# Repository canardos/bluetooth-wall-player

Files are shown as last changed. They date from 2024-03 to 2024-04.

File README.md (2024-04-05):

# Bluetooth Wall Audio Player

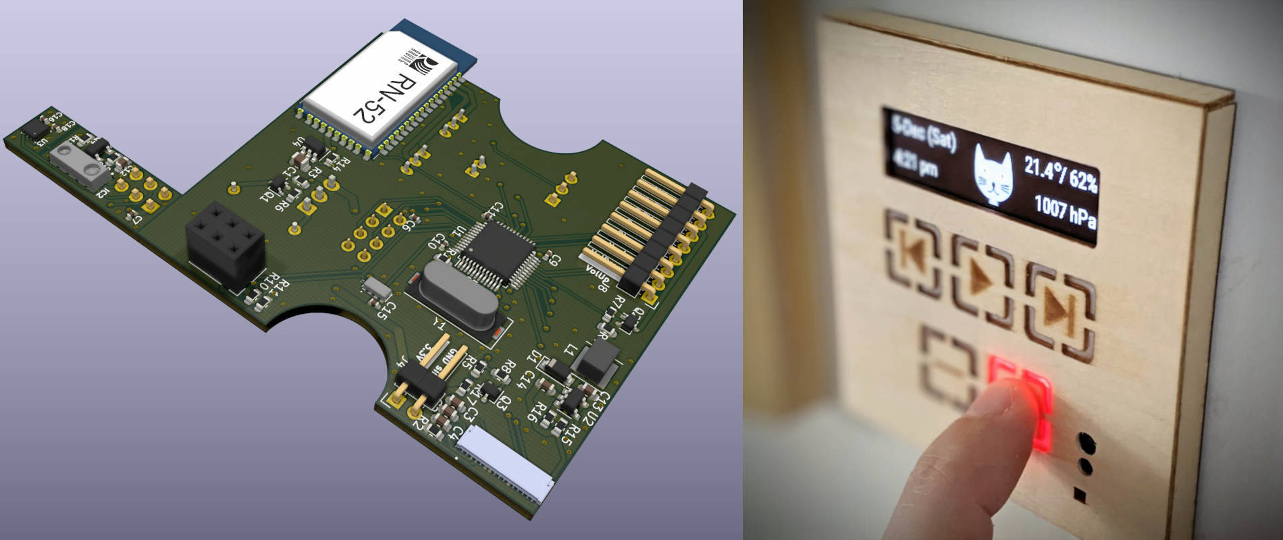
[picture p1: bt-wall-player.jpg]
Bluetooth audio player


## A low power, wall mounted, Bluetooth audio player, clock, and environmental monitor

> [!Warning]
> This is personal project. It was built and works without issue for my purposes. It is made public here in case some part of it is useful to others, but **neither the hardware nor firmware have been rigorously tested**.

**Features:**

- Media/volume controls
- Song metadata display
- Time, temperature, pressure, humidity display on idle
- Ultra low power sleep with proximity sensing wakeup
- Differential analog and S/PDIF digital audio output

**This repo contains the firmware and PCB/enclosure design.**

**See [custom electronics projects at duk.io](https://www.duk.io/blog/electronics-projects/) for full project details.**

## Build

The project uses the [PlatformIO](https://platformio.org/) dependency management/build system. If you have PlatformIO installed, executing the `run` command in the root folder *should* 🙏 be all that is required for a successful build. The `platformio.ini` file contains the required configuration  and PlatformIO will download the required platform dependencies and toolchain.

**1. Clone repo and download submodules**

```shell
> git clone https://github.com/canardos/bluetooth-wall-player.git
> cd bluetooth-wall-player
> git submodule update --init
```

**2. Build firmware (PlatformIO must be installed)**

```shell
> pio run

```

**3. Upload to device**

Similarly, use `pio run --target upload` to upload the firmware to the device. You'll likely need to update the upload settings in `platformio.ini` to reflect your settings, or use your own upload tool.

```shell
> pio run --target upload

```

**4. [optional] Create project files for IDE**

If you want to view/edit the project in your favorite IDE, use PlatformIO to generate the appropriate setup/workspace files and import the project:

```shell
> pio project init --ide [atom|clion|codeblocks|eclipse|emacs|netbeans|qtcreator|sublimetext|vim|visualstudio|vscode]
```

See the [PlatformIO documentation](https://docs.platformio.org) for further details.

#### Using an alternate build system

**Platform dependencies**

If you wish to use a different build system, you will need:

| | |
|-|-|
| ST STM32 CMSIS headers | Peripheral/register definitions |
| CMSIS headers/source | CMSIS HAL functionality - SysTick_Config, NVIC_xxx etc.|
| CMSIS Cortex-M3 system source | `SystemInit()`/`SystemCoreClockUpdate()` implementation and `SystemCoreClock`|
| Startup source file | ASM file containing the startup code and vector table |
| Linker script | Tells the linker how to setup everything in flash/SRAM |

All of these are available in the [STM32 SDK](https://www.st.com/en/development-tools/stm32-software-development-tools.html) available from ST Micro.

**Compiling / linking**

`platformio.ini` lists the required compiler flags. Be sure to use `--specs=nano.specs` and `--specs=nosys.specs` when linking using your own tools.

#### Compiler

The project was built with `gcc-arm-none-eabi 9.2.1` It should work with any later GCC version and possibly with other compilers. The code contains some GCC flags and some C99 VLAs.

#### Target requirements

| | |
|-|-|
|MCU  | STM32F1xx |
|Flash| >42kb |
|SRAM | >8kb |

## Dependencies (firmware)

**CMSIS**

PlatformIO should automatically include/link the correct headers/sources from the STM32 SDK. Version 9.0.0 was used in production.

**Libpekin**

[Libpekin](https://github.com/canardos/libpekin) is a collection of shared MCU-related code resulting from this and other projects. It's included as a Git submodule in the `lib` folder. PlatformIO will include the `lib` subfolders automatically.

## Hardware

#### PCB

The PCB was designed with KiCad v.5, but the files have been upgraded to v.7 and are located in `/hardware/pcb`. Gerber output for the first revision is located in `/hardware/pcb/plots_rev_a`.

> [!Important]
> [Several fixes have been made to the design](https://www.duk.io/blog/electronics-projects/bt-player/bluetooth-audio-player-conclusion/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), which are implemented in the latest schematic/pcb files, but are not present in the revision A plot output.

See the [KiCad documentation](https://docs.kicad.org/) for information on installing and using KiCad.

**Custom symbols and footprints required by the board are included as a Git submodule at `/hardware/pcb/kicad-mycustom-lib`, and are included in the KiCad project as a project-specific library.**

#### Enclosure

The [enclosure design](http://www.duk.io/blog/electronics-projects/bt-player/bluetooth-audio-player-mechanical-design/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) includes a [laser-cut wooden facade](http://www.duk.io/blog/electronics-projects/bt-player/bluetooth-audio-player-mechanical-design/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). The CAD files for the design are located in `/hardware/enclosure/laser_cut_facade`.

A Sketchup model I used to model the mechanical constraints of the design is included in `/hardware/enclosure`.

## Folder structure

```
BTWallPlayer
|
+--artwork           | SVG sources for animation
|  |
|  +--render         | bitmap output frames
|
+--hardware
|  |
|  +--pcb           | KiCad schematic and board design files
|  +--enclosure     | Enclosure Sketchup model and laser cutting
|                   | design files
|
+--lib
|  |
|  +--libpekin       | Libpekin platform independent code
|  +--libpekin_stm32 | Libpekin STM32 specific code
|
+--src
|  |
|  +--data           | Image and font data
|  +--devices        | Hardware device drivers
|
|--test              | No tests in use

```

## License

This software is available under the [MIT license](https://opensource.org/license/MIT).

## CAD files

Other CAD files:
hardware/enclosure/bt-wall-player.skp

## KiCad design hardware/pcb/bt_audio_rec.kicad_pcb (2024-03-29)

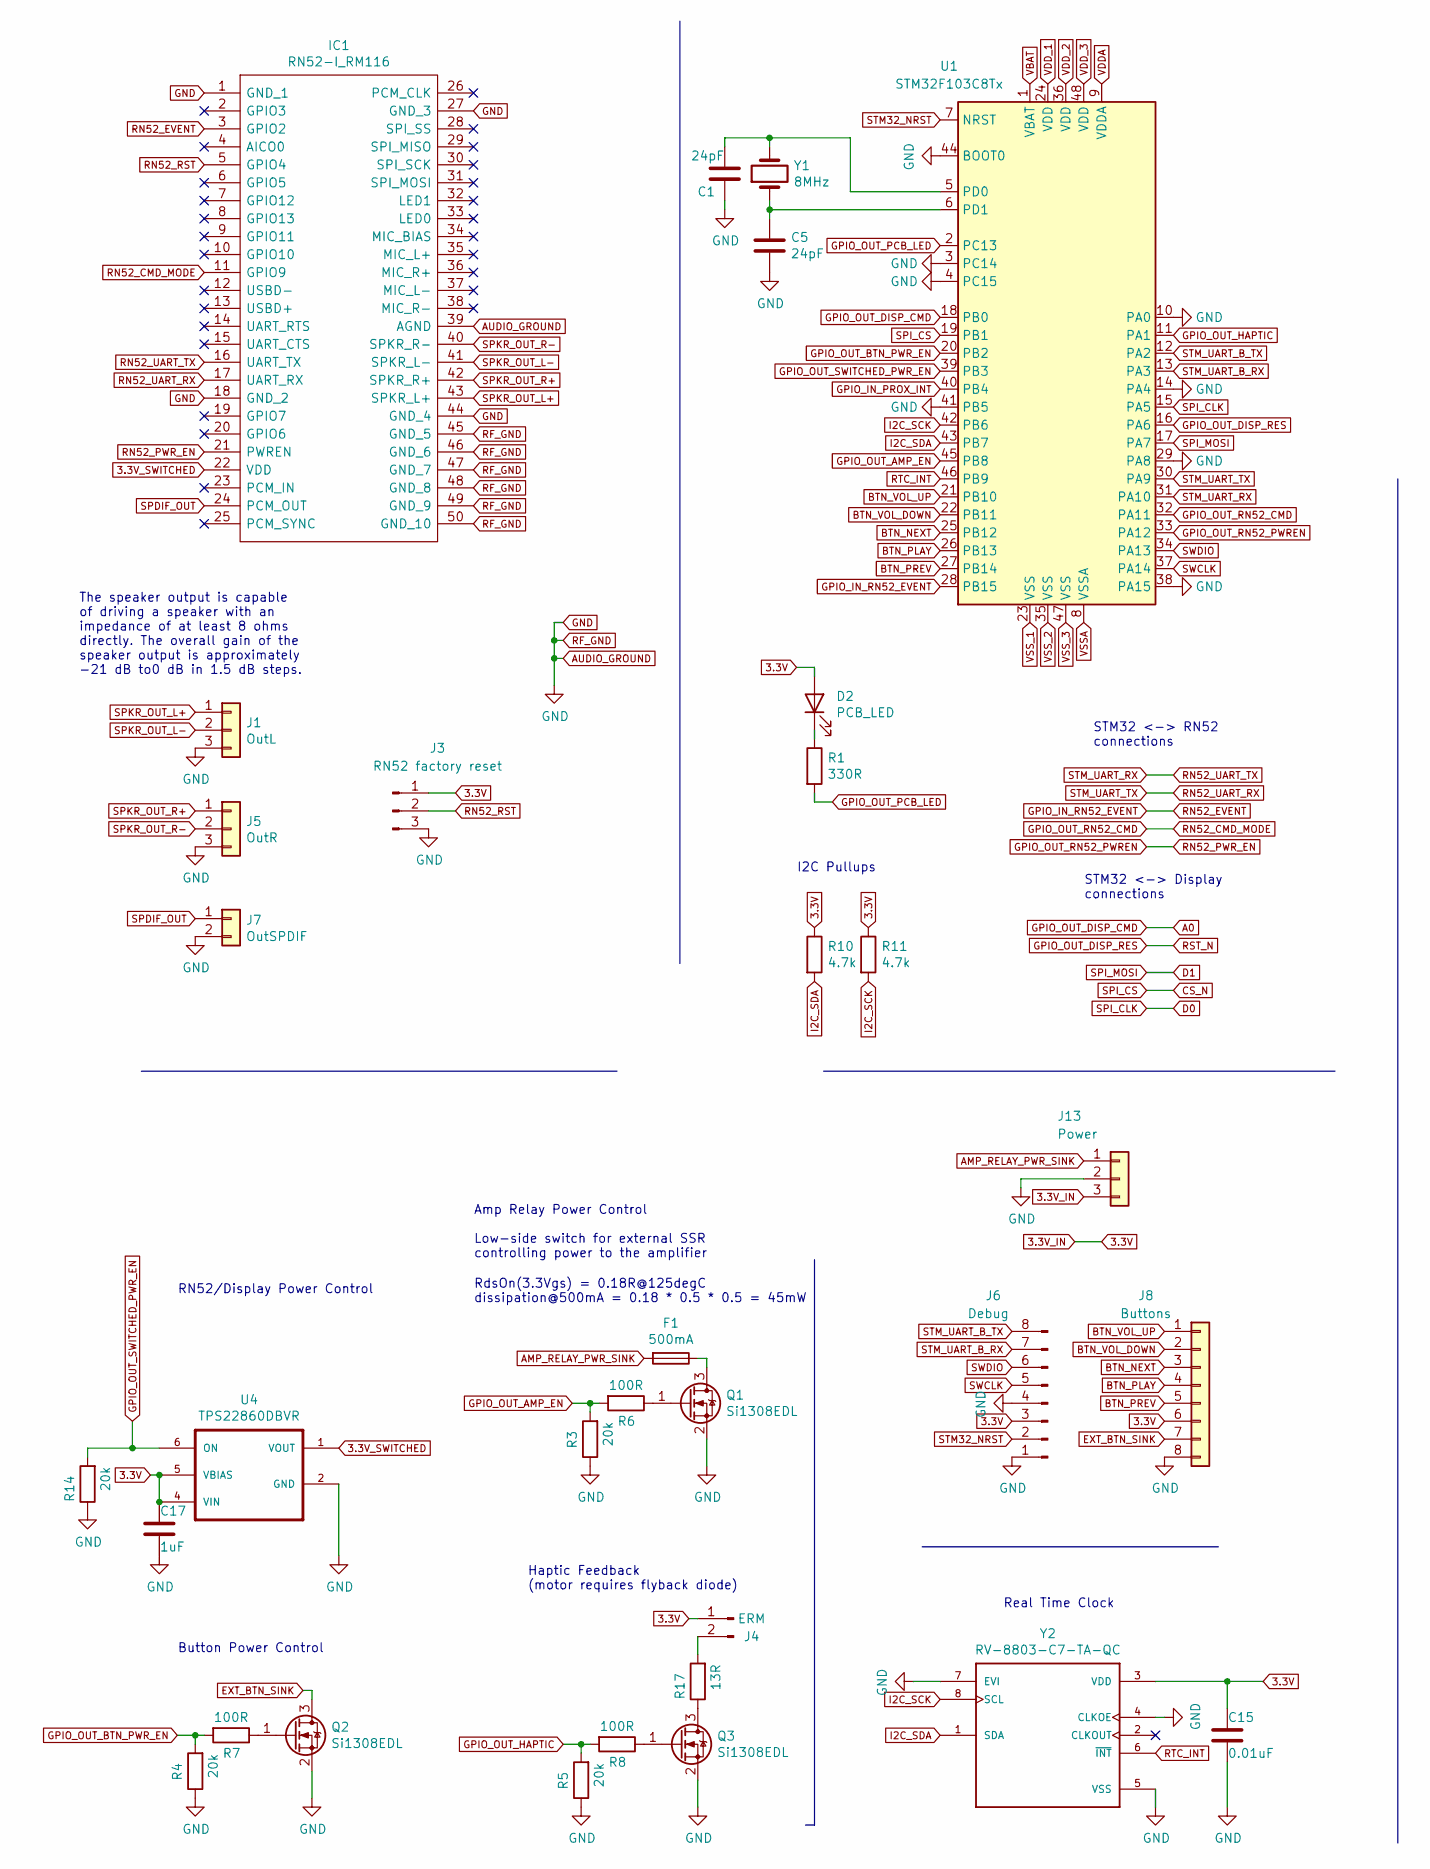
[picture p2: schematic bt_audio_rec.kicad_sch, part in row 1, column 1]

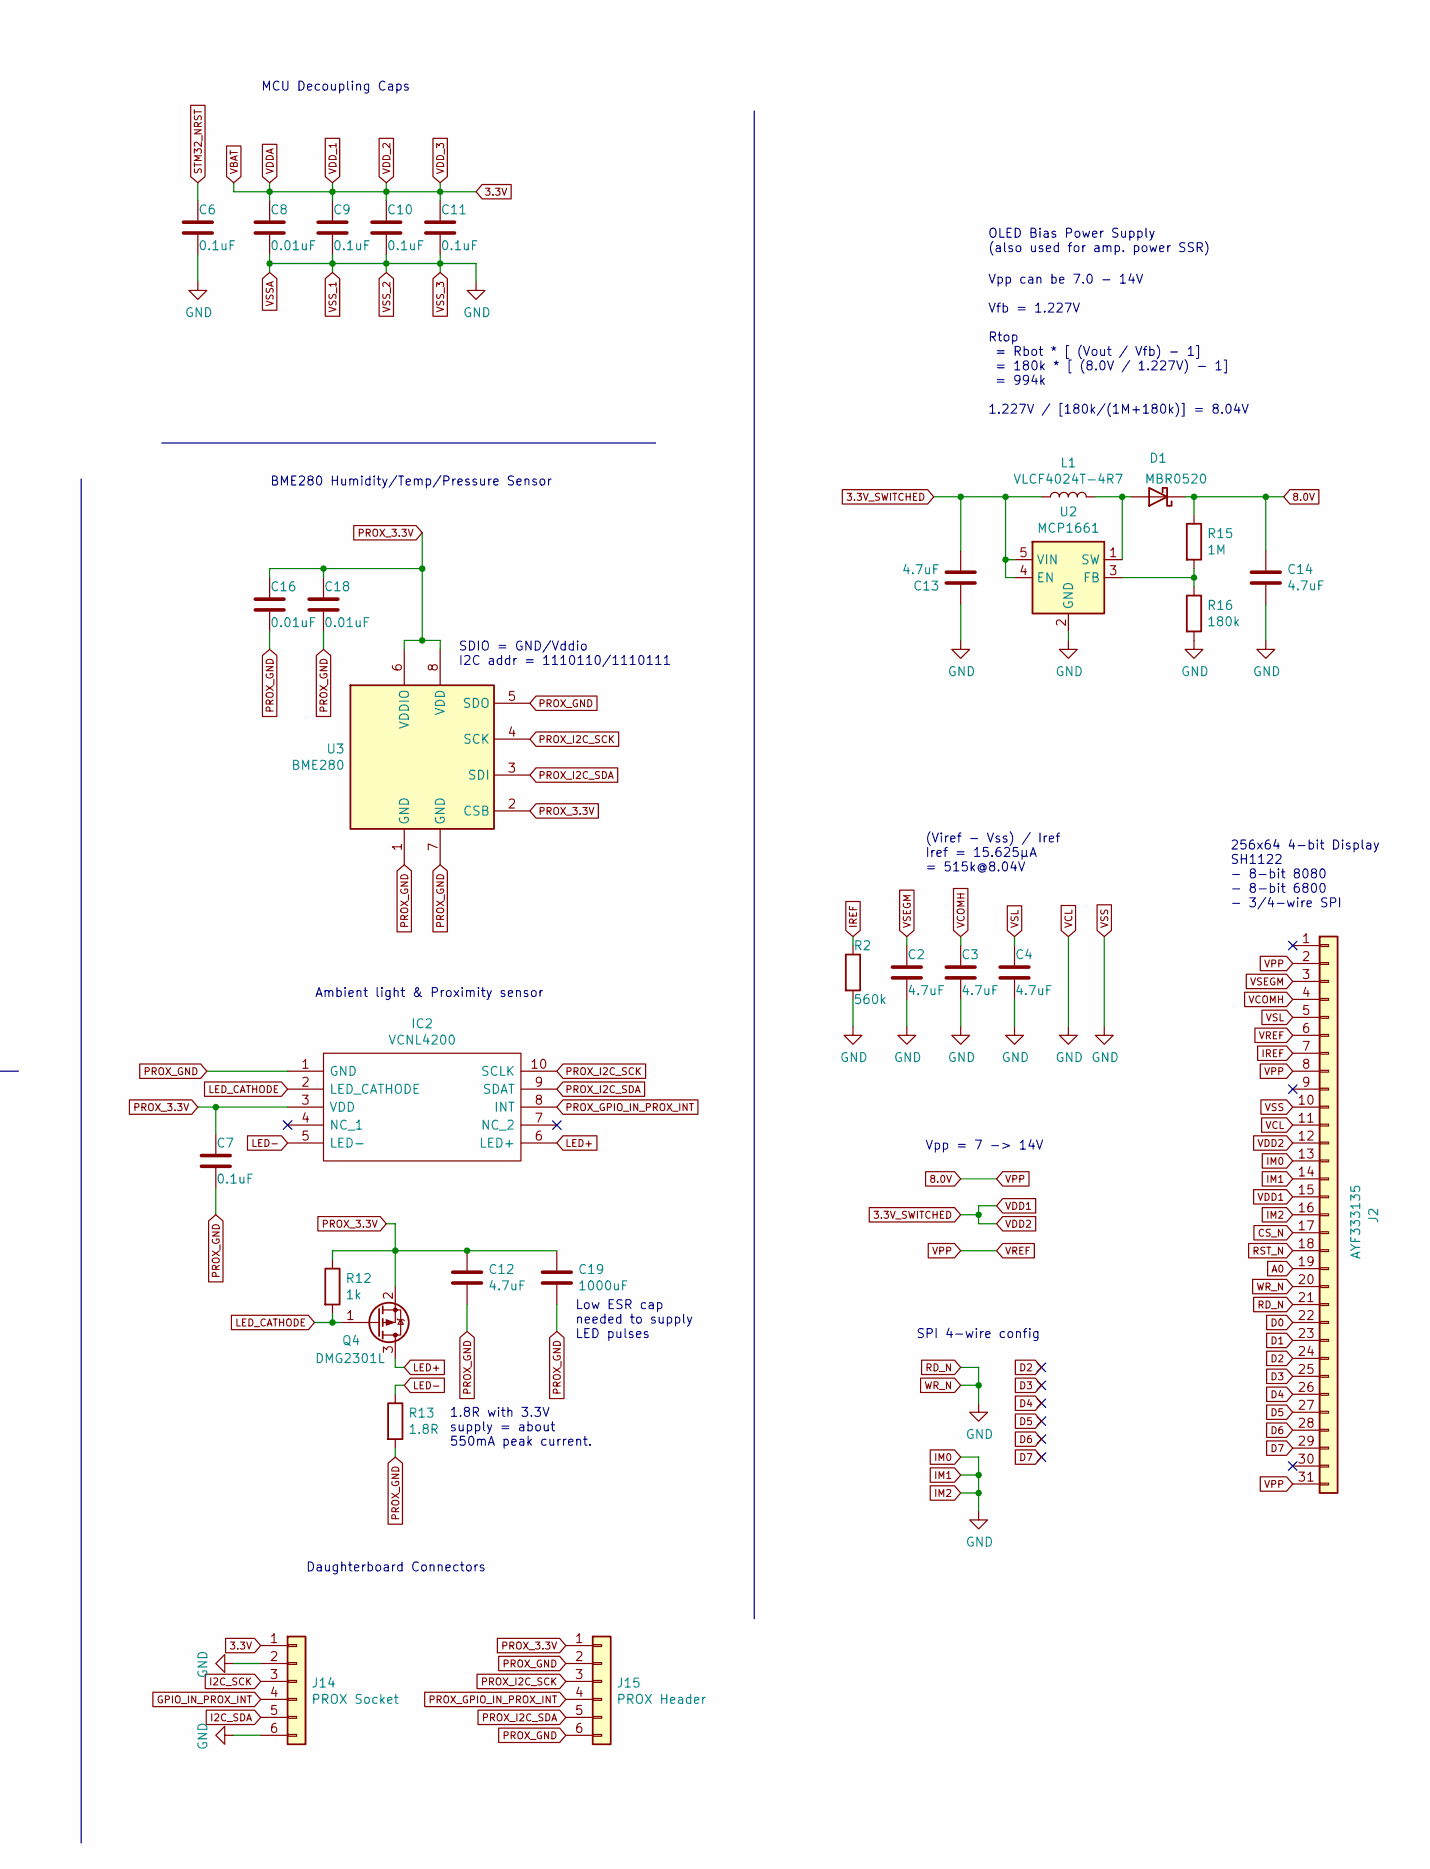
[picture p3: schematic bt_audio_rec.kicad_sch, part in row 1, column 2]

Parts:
C1, C5: 24pF; C_0402_1005Metric
C2, C3, C4, C12, C13, C14: 4.7uF; C_0603_1608Metric
C6, C7, C9, C10, C11: 0.1uF; C_0402_1005Metric
C8, C15, C16, C18: 0.01uF; C_0402_1005Metric
C17: 1uF; C_0805_2012Metric
C19: 1000uF; C_Radial_D6.3mm_H7.0mm_P2.50mm
D1: MBR0520; D_SOD-123
D2: PCB_LED; D_0603_1608Metric
F1: 500mA; R_Axial_DIN0207_L6.3mm_D2.5mm_P10.16mm_Horizontal
IC1: RN52-I_RM116; Bluetooth_module_Microchip_RN52; Manufacturer_Part_Number RN52-I/RM116; Mouser Part Number 579-RN52-I/RM116
IC2: VCNL4200; Proximity_Sensor_Vishay_VCNL4200; Manufacturer_Part_Number VCNL4200; Mouser Part Number 78-VCNL4200
J1: OutL; JST_PH_B3B-PH-K_1x03_P2.00mm_Vertical
J2: AYF333135; FPC_Socket_0.3_31_Panasonic_AYF333135
J3: RN52 factory reset; PinHeader_1x03_P2.54mm_Horizontal
J4: ERM; PinHeader_1x02_P2.54mm_Horizontal
J5: OutR; JST_PH_B3B-PH-K_1x03_P2.00mm_Vertical
J6: Debug; PinSocket_2x04_P2.54mm_Vertical
J7: OutSPDIF; JST_PH_B2B-PH-K_1x02_P2.00mm_Vertical
J8: Buttons; PinHeader_1x08_P2.54mm_Horizontal
J13: Power; Molex_KK-254_AE-6410-03A_1x03_P2.54mm_Vertical
J14: PROX Socket; PinSocket_2x03_P2.54mm_Vertical
J15: PROX Header; PinHeader_2x03_P2.54mm_Vertical
L1: VLCF4024T-4R7; Inductor_L_TDK_VLCF4024
Q1, Q2, Q3: Si1308EDL; SOT-323_SC-70
Q4: DMG2301L; SOT-23
R1: 330R; R_0603_1608Metric
R2: 560k; R_0603_1608Metric
R3, R4, R5, R14: 20k; R_0603_1608Metric
R6, R7, R8: 100R; R_0603_1608Metric
R10, R11: 4.7k; R_0603_1608Metric
R12: 1k; R_0603_1608Metric
R13: 1.8R; R_0603_1608Metric
R15: 1M; R_0603_1608Metric
R16: 180k; R_0603_1608Metric
R17: 13R; R_0603_1608Metric
U1: STM32F103C8Tx; LQFP-48_7x7mm_P0.5mm
U2: MCP1661; SOT-23-5
U3: BME280; Bosch_LGA-8_2.5x2.5mm_P0.65mm_ClockwisePinNumbering
U4: TPS22860DBVR; SOT-23-6
Y1: 8MHz; Crystal_SMD_HC49-SD
Y2: RV-8803-C7-TA-QC; RTC_Microcrystal_RV-8803-C7-TA-QC

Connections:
3.3V: C8.1, C9.1, C10.1, C11.1, C15.1, C17.1, D2.2 (A), J3.1, J4.1, J6.3, J8.6, J13.3, J14.1, R10.1, R11.1, U1.1 (VBAT), U1.9 (VDDA), U1.24 (VDD), U1.36 (VDD), U1.48 (VDD), U4.4 (VIN), U4.5 (VBIAS), Y2.3 (VDD)
3.3V_SWITCHED: C13.2, IC1.22 (VDD), J2.12, J2.15, L1.1, U2.4 (EN), U2.5 (VIN), U4.1 (VOUT)
8.0V: C14.1, D1.1 (K), J2.2, J2.6, J2.8, J2.31, R15.1
A0: J2.19, U1.18 (PB0)
AMP_RELAY_PWR_SINK: F1.2, J13.1
AUDIO_GROUND: C1.1, C2.2, C3.2, C4.2, C5.2, C6.2, C8.2, C9.2, C10.2, C11.2, C13.1, C14.2, C15.2, C17.2, IC1.1 (GND_1), IC1.18 (GND_2), IC1.27 (GND_3), IC1.39 (AGND), IC1.44 (GND_4), IC1.45 (GND_5), IC1.46 (GND_6), IC1.47 (GND_7), IC1.48 (GND_8), IC1.49 (GND_9), IC1.50 (GND_10), J1.3, J2.10, J2.11, J2.13, J2.14, J2.16, J2.20, J2.21, J3.3, J5.3, J6.1, J6.4, J7.2, J8.8, J13.2, J14.2, J14.6, Q1.2 (S), Q2.2 (S), Q3.2 (S), R2.2, R3.1, R4.1, R5.1, R14.1, R16.2, U1.3 (PC14), U1.4 (PC15), U1.8 (VSSA), U1.10 (PA0), U1.14 (PA4), U1.23 (VSS), U1.29 (PA8), U1.35 (VSS), U1.38 (PA15), U1.41 (PB5), U1.44 (BOOT0), U1.47 (VSS), U2.2 (GND), U4.2 (GND), Y2.4 (CLKOE), Y2.5 (VSS), Y2.7 (EVI)
BTN_NEXT: J8.3, U1.25 (PB12)
BTN_PLAY: J8.4, U1.26 (PB13)
BTN_PREV: J8.5, U1.27 (PB14)
BTN_VOL_DOWN: J8.2, U1.22 (PB11)
BTN_VOL_UP: J8.1, U1.21 (PB10)
CS_N: J2.17, U1.19 (PB1)
D0: J2.22, U1.15 (PA5)
D1: J2.23, U1.17 (PA7)
D2: J2.24
D3: J2.25
D4: J2.26
D5: J2.27
D6: J2.28
D7: J2.29
EXT_BTN_SINK: J8.7, Q2.3 (D)
GPIO_IN_PROX_INT: J14.4, U1.40 (PB4)
GPIO_IN_RN52_EVENT: IC1.3 (GPIO2), U1.28 (PB15)
GPIO_OUT_AMP_EN: R3.2, R6.2, U1.45 (PB8)
GPIO_OUT_BTN_PWR_EN: R4.2, R7.2, U1.20 (PB2)
GPIO_OUT_DISP_RES: J2.18, U1.16 (PA6)
GPIO_OUT_HAPTIC: R5.2, R8.2, U1.11 (PA1)
GPIO_OUT_PCB_LED: R1.2, U1.2 (PC13)
GPIO_OUT_RN52_CMD: IC1.11 (GPIO9), U1.32 (PA11)
GPIO_OUT_RN52_PWREN: IC1.21 (PWREN), U1.33 (PA12)
GPIO_OUT_SWITCHED_PWR_EN: R14.2, U1.39 (PB3), U4.6 (ON)
I2C_SCK: J14.3, R11.2, U1.42 (PB6), Y2.8 (SCL)
I2C_SDA: J14.5, R10.2, U1.43 (PB7), Y2.1 (SDA)
IREF: J2.7, R2.1
LED+: IC2.6 (LED+), Q4.3 (D)
LED-: IC2.5 (LED-), R13.1
LED_CATHODE: IC2.2 (LED_CATHODE), Q4.1 (G), R12.2
unnamed: C1.2, U1.5 (PD0), Y1.2
unnamed: C5.1, U1.6 (PD1), Y1.1
unnamed: D1.2 (A), L1.2, U2.1 (SW)
unnamed: D2.1 (K), R1.1
unnamed: F1.1, Q1.3 (D)
unnamed: J4.2, R17.2
unnamed: Q1.1 (G), R6.1
unnamed: Q2.1 (G), R7.1
unnamed: Q3.1 (G), R8.1
unnamed: Q3.3 (D), R17.1
unnamed: R15.2, R16.1, U2.3 (FB)
PROX_3.3V: C7.1, C12.1, C16.1, C18.1, C19.1, IC2.3 (VDD), J15.1, Q4.2 (S), R12.1, U3.2 (CSB), U3.6 (VDDIO), U3.8 (VDD)
PROX_GND: C7.2, C12.2, C16.2, C18.2, C19.2, IC2.1 (GND), J15.2, J15.6, R13.2, U3.1 (GND), U3.5 (SDO), U3.7 (GND)
PROX_GPIO_IN_PROX_INT: IC2.8 (INT), J15.4
PROX_I2C_SCK: IC2.10 (SCLK), J15.3, U3.4 (SCK)
PROX_I2C_SDA: IC2.9 (SDAT), J15.5, U3.3 (SDI)
RN52_RST: IC1.5 (GPIO4), J3.2
RN52_UART_RX: IC1.17 (UART_RX), U1.30 (PA9)
RN52_UART_TX: IC1.16 (UART_TX), U1.31 (PA10)
RTC_INT: U1.46 (PB9), Y2.6 (~INT)
SPDIF_OUT: IC1.24 (PCM_OUT), J7.1
SPKR_OUT_L+: IC1.43 (SPKR_L+), J1.1
SPKR_OUT_L-: IC1.41 (SPKR_L-), J1.2
SPKR_OUT_R+: IC1.42 (SPKR_R+), J5.1
SPKR_OUT_R-: IC1.40 (SPKR_R-), J5.2
STM32_NRST: C6.1, J6.2, U1.7 (NRST)
STM_UART_B_RX: J6.7, U1.13 (PA3)
STM_UART_B_TX: J6.8, U1.12 (PA2)
SWCLK: J6.5, U1.37 (PA14)
SWDIO: J6.6, U1.34 (PA13)
VCOMH: C3.1, J2.4
VSEGM: C2.1, J2.3
VSL: C4.1, J2.5

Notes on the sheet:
Haptic Feedback (motor requires flyback diode)
Daughterboard Connectors
I2C Pullups
Amp Relay Power Control Low-side switch for external SSR controlling power to the amplifier
Vpp can be 7.0 - 14V Vfb = 1.227V Rtop = Rbot * [ (Vout / Vfb) - 1] = 180k * [ (8.0V / 1.227V) - 1] = 994k 1.227V / [180k/(1M+180k)] = 8.04V
BME280 Humidity/Temp/Pressure Sensor
SDIO = GND/Vddio I2C addr = 1110110/1110111
(Viref - Vss) / Iref Iref = 15.625μA = 515k@8.04V
The speaker output is capable of driving a speaker with an impedance of at least 8 ohms directly. The overall gain of the speaker output is approximately -21 dB to0 dB in 1.5 dB steps.
Low ESR cap needed to supply LED pulses
Button Power Control
RdsOn(3.3Vgs) = 0.18R@125degC dissipation@500mA = 0.18 * 0.5 * 0.5 = 45mW
1.8R with 3.3V supply = about 550mA peak current.
Vpp = 7 -> 14V
STM32 <-> Display connections
Ambient light & Proximity sensor
RN52/Display Power Control
OLED Bias Power Supply (also used for amp. power SSR)
Real Time Clock
STM32 <-> RN52 connections
256x64 4-bit Display SH1122 - 8-bit 8080 - 8-bit 6800 - 3/4-wire SPI
MCU Decoupling Caps
SPI 4-wire config

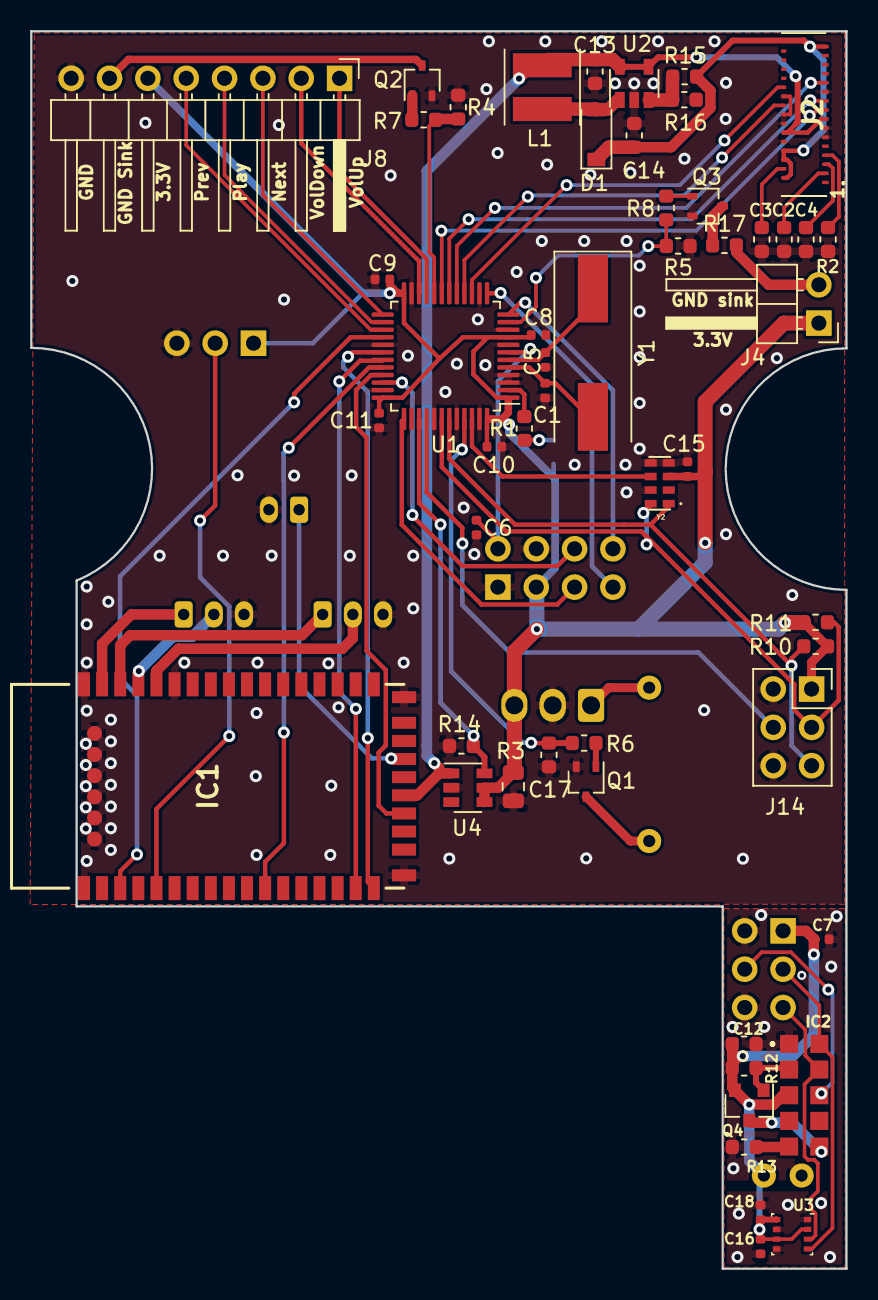
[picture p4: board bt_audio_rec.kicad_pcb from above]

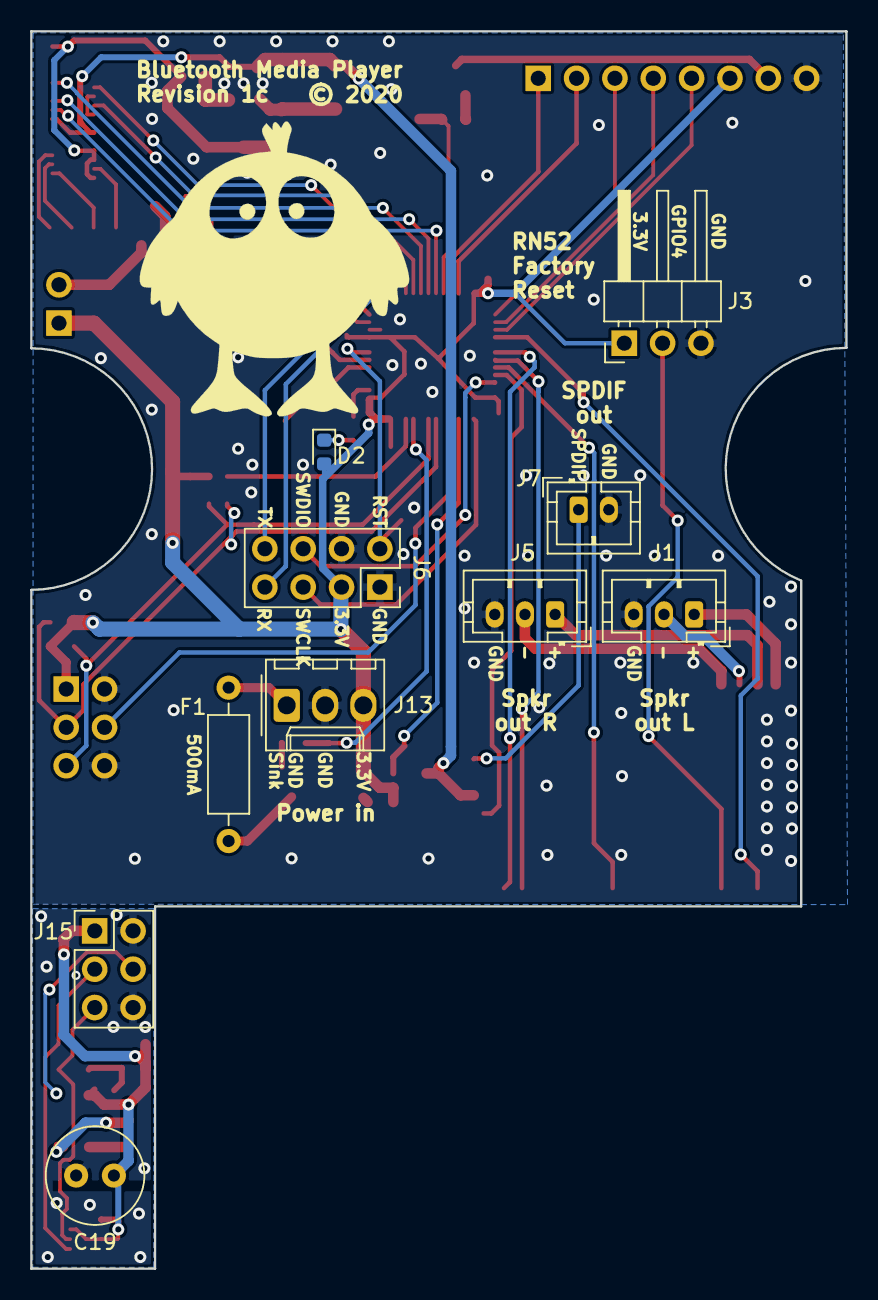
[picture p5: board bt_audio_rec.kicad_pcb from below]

Board: 2 copper layers, 54.0 x 82.0 mm, 62 parts (10 on the bottom side), 64 nets.

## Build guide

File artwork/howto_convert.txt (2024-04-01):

To convert a portion of the SVG to a 4-bit bitmap source for use with Libpekin:

1) Export PNG from inkscape
2) magick cat.png -depth 4 gray:cat.dat
3) xxd -i cat.dat > cat.h

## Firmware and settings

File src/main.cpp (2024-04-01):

#include "libpekin.h"
#include "string_util.h"
#include "libpekin_stm32_hal.h"
#include "clock_stm32f1xx.h"

#include <bt_module.h>
#include <error_handler.h>
#include <event_queue.h>
#include <player_state_machine.h>

#include <devices/peripherals.h>
#include <devices/rn52.h>
#include "devices/oled.h"
#include "devices/sensors.h"
#include "devices/rtc.h"

/*
3.3V / GND / sink
blue /white/brown, left to right front of faceplate
brown/black/blue cable
*/

using namespace Libp;
using namespace LibpStm32;

static BtModule bt_module_(getRn52());
static Display display(getOled());
static PwrControl pwr_ctrl;
static EventQueue queue_;
static PlayerStateMachine player(queue_, bt_module_, display, pwr_ctrl);

void initSysClock()
{
    Clk::setSysClk(Clk::SysClkSrc::ext_high_speed_osc, 2, Clk::PllSrc::hse, 2);
    // 24 MHz
    Clk::setSysClk(Clk::SysClkSrc::pll, 2, Clk::PllSrc::hse, 3);
    // APB1 can't exceed 36 MHz
    Clk::setPeripheralClk(Clk::ApbPrescaler::div1, Clk::ApbPrescaler::div1);
}

void initSensors()
{
    if (!initTempSensor()) {
        getErrHndlr().halt(ErrorCode::module_init_fail, "BME280 init failed");
    }
    if (!initRtc()) {
        getErrHndlr().halt(ErrorCode::module_init_fail, "RTC init failed");
    }

    display.drawText(Display::TextPos::fullscreen, "Calibrating proximity", "in 3");
    delayMs(1000);
    display.drawText(Display::TextPos::fullscreen, "Calibrating proximity", "in 2");
    delayMs(1000);
    display.drawText(Display::TextPos::fullscreen, "Calibrating proximity", "in 1");
    delayMs(1000);

    uint16_t prox_count = initProxSensor();
    if (prox_count == 0) {
        getErrHndlr().halt(ErrorCode::module_init_fail, "Prox init failed");
    }

    constexpr uint8_t max_len = strlen("Done ()") + Libp::maxStrLen<uint16_t>();
    char buf[max_len];
    snprintf(buf, max_len, "Done (%d)", prox_count);
    display.drawText(Display::TextPos::fullscreen, buf, "Initializing Bluetooth...");

    TimeData time_data = {0};
    time_data.year = 20;
    time_data.month = 1;
    time_data.day_of_month = 1;
    setTime(time_data);
}

//#define TEST_PROX_MODE

#ifdef TEST_PROX_MODE
void drawProx()
{
    char buf[50];
    while (true) {
        uint16_t count = getProxCount();
        snprintf(buf, 50, "Count: %d", count);
        display.drawText(Display::TextPos::fullscreen, buf, "");
        delayMs(300);
    }
}
#endif

void initPeripherals()
{
    initGpio();  // enable GPIO clocks before peripherals init
    initSerial();
    initSpi();
    initI2c();
    initTimers();
    initErrHndlr();
}

int main(void)
{
    initSysClock();
    libpekinInitTimers();
    initPeripherals();
    pwr_ctrl.setState(PwrControl::PwrState::clock); // needs errHndlr
    oledInit();                                     // needs SPI and timers
    initSensors();                                  // needs I2C, timers, and display
#ifdef TEST_PROX_MODE
    drawProx();
#endif
    initRn52();
    if (!bt_module_.init()) {
        getErrHndlr().halt(ErrorCode::module_init_fail, "BT init failed");
    }
    enableExtIrqs();
    clearProxInterrupt();
    player.run();
}

#ifdef __cplusplus
extern "C" {
#endif

/// Triggered by RN52 event on GPIO2 and button presses
__attribute__ ((interrupt("IRQ")))
void EXTI15_10_IRQHandler(void)
{
    disableExtIrqs();
    getErrHndlr().report("\r\nEXTI15_10_IRQ\r\n");

    // --- RN52 event ---

    if (Pins::rn52_gpio2.irqIsPending()) {
        queue_.postEvent(EventType::rn52_gpio2);
        Pins::rn52_gpio2.clearPendingIrqBit();
    }

    // --- Button events ---

    if (Pins::btn_play.irqIsPending()) {
        bool pressed = Pins::btn_play.read();
        getErrHndlr().report("Play: %d\r\n", (int)pressed);
        queue_.postEvent(pressed ? EventType::btn_play : EventType::btn_play_release);
        Pins::btn_play.clearPendingIrqBit();
    }
    if (Pins::btn_vol_up.irqIsPending()) {
        queue_.postEvent(EventType::btn_vol_up);
        Pins::btn_vol_up.clearPendingIrqBit();
    }
    if (Pins::btn_vol_dn.irqIsPending()) {
        queue_.postEvent(EventType::btn_vol_dn);
        Pins::btn_vol_dn.clearPendingIrqBit();
    }
    if (Pins::btn_next.irqIsPending()) {
        queue_.postEvent(EventType::btn_next);
        Pins::btn_next.clearPendingIrqBit();
    }
    if (Pins::btn_prev.irqIsPending()) {
        queue_.postEvent(EventType::btn_prev);
        Pins::btn_prev.clearPendingIrqBit();
    }
    Pins::btn_prev.clearPendingIrqLine();
    //__DSB();
    enableExtIrqs();
}

/// Triggered by RTC minute tick
__attribute__ ((interrupt("IRQ")))
void EXTI9_5_IRQHandler(void)
{
    getErrHndlr().report("\r\nEXTI9_5_IRQ\r\n");
    if (Pins::rtc_int.irqIsPending()) {
        queue_.postEvent(EventType::clock_tick);
        Pins::rtc_int.clearPendingIrqBit();
    }
    Pins::rtc_int.clearPendingIrqLine();
    __DSB();
}

/// Triggered by proximity sensor
__attribute__ ((interrupt("IRQ")))
void EXTI4_IRQHandler(void)
{
    getErrHndlr().report("\r\nEXTI4_IRQ\r\n");
    if (Pins::proximity_int.irqIsPending()) {
        queue_.postEvent(EventType::proximity_trigger);
        Pins::proximity_int.clearPendingIrqBit();
    }
    Pins::proximity_int.clearPendingIrqLine();
    __DSB();
}

#ifdef __cplusplus
}
#endif

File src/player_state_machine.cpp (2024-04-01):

#include <event_queue.h>
#include <devices/peripherals.h>
#include <devices/haptic.h>
#include <devices/rtc.h>
#include <devices/sensors.h>
#include <display.h>
#include <player_state_machine.h>

using namespace Libp;

PlayerStateMachine::PlayerStateMachine(EventQueue& event_queue,
        BtModule& bt_module, Display& display, PwrControl& pwr_ctrl)
            : event_queue_(event_queue), bt_module_(bt_module),
              display_(display), pwr_ctrl_(pwr_ctrl) { }

// Main program loop
void PlayerStateMachine::run()
{
    pwr_ctrl_.resetInactivityTimer();
    display_.notifyNewModuleState(ModuleState::disconnected, ModuleState::disconnected);
    event_queue_.postEvent(EventType::clock_tick); // paint clock
    while (true) {

        while(event_queue_.eventIsPending())
            processEvent(event_queue_.getNextPendingEvent());

        // Flag set by transition to disconnected state.
        // Need to wait on disconnect animation if we were previously connected
        if (draw_clock_when_display_ready_ && display_.disconnectAnimIsDone() ) {
            draw_clock_when_display_ready_ = false;
            // Start clock animation
            display_.notifyNewModuleState(ModuleState::disconnected, ModuleState::disconnected);
            event_queue_.postEvent(EventType::clock_tick);
        }
        // Detect long press of play button
        if (last_play_press_ms) {
            static constexpr uint32_t long_press_duration_ms = 2000;
            uint32_t now_ms = getMillis();
            if ( (now_ms - last_play_press_ms) > long_press_duration_ms) {
                event_queue_.postEvent(EventType::btn_play_long_press);
                last_play_press_ms = 0;
            }
        }

        if (player_state_ == PlayerState::pairing_listening)
            handlePairingModeListening();

        display_.update();
        oledUpdateBrightness( getLightLvl() );
        sleepIfInactive();

        delayMs(5);
    }
}

static uint32_t lastWakeTime = 0;

void PlayerStateMachine::sleepIfInactive()
{
    if (module_state_ == ModuleState::disconnected && pwr_ctrl_.timeToSleep()) {
        player_state_ = PlayerState::normal;
        pwr_ctrl_.sleep();
        lastWakeTime = getMillis();
        event_queue_.postEvent(EventType::clock_tick);
    }
}

void PlayerStateMachine::processEvent(EventQueue::Event event)
{
    getErrHndlr().report("SM: new event (%s)\r\n", event_type_names[enumBaseT(event.event_)]);
    if (event.event_ != EventType::clock_tick)
        pwr_ctrl_.resetInactivityTimer();

    switch (event.event_) {
    case EventType::rn52_gpio2:
        handleGpio2Event();
        break;
    case EventType::rn52_state_chg:
        handleModuleStateChg(event.new_state_);
        break;
    case EventType::track_chg:
        if (module_state_ == ModuleState::connected_streaming)
            handleTrackChange();
        break;
    case EventType::proximity_trigger:
        clearProxInterrupt();
        // nothing else to do, inactivity timer already reset above
        break;
    case EventType::clock_tick:
        handleClockTick();
        break;
    case EventType::btn_play:
    case EventType::btn_next:
    case EventType::btn_prev:
    case EventType::btn_vol_up:
    case EventType::btn_vol_dn:
    case EventType::btn_play_release:
    case EventType::btn_play_long_press:
        handleBtnPress(event);
        break;
    case EventType::do_nothing_event:
        // nothing to do
        break;
    }
}

void PlayerStateMachine::handleClockTick()
{
    if (module_state_ != ModuleState::disconnected)
        return;

    TimeData time_data;
    EnvData env_data;
    const uint32_t secsActive = (getMillis() - lastWakeTime) / 1000;
    bool success = getTime(time_data) && getTemp(env_data, secsActive);
    if (!success)
        getErrHndlr().halt(ErrCode::i2c, "Sensor failure");

    // Don't draw clock if we are still animating disconnect
    if (!draw_clock_when_display_ready_)
        display_.drawClockAndWeather(time_data, env_data);
}

void PlayerStateMachine::handleBtnPress(EventQueue::Event event)
{
    constexpr bool enable_haptic = false;

    if constexpr (enable_haptic) {
        constexpr uint16_t haptic_duration_ms = 80;
        if (event.event_ != EventType::btn_play_release)
            triggerHaptic(haptic_duration_ms);
    }

    // Track long press for play button
    if (event.event_ == EventType::btn_play)
        last_play_press_ms = getMillis();
    else if (event.event_ == EventType::btn_play_release)
        last_play_press_ms = 0;

    // Delegate to handler for the current state
    (this->*btn_handlers_[enumBaseT(player_state_)])(event);
}

void PlayerStateMachine::handleBtnNormal(EventQueue::Event event)
{
    switch (module_state_) {
    case ModuleState::disconnected:
        if (event.event_ == EventType::btn_play_long_press)
            enterMenuMode();
        break;
    case ModuleState::pairing:
        break;
    case ModuleState::connected:
    case ModuleState::connected_streaming:
        switch(event.event_) {
        case EventType::btn_vol_up:
            bt_module_.volUp();
            break;
        case EventType::btn_vol_dn:
            bt_module_.volDown();
            break;
        case EventType::btn_next:
            bt_module_.trackNext();
            break;
        case EventType::btn_prev:
            bt_module_.trackPrev();
            break;
        case EventType::btn_play:
            bt_module_.playPause();
            break;
        case EventType::btn_play_long_press:
        case EventType::btn_play_release:
            break;
        // Illegal states
        case EventType::rn52_gpio2:
        case EventType::rn52_state_chg:
        case EventType::track_chg:
        case EventType::proximity_trigger:
        case EventType::clock_tick:
        case EventType::do_nothing_event:
            break;
        }
        break;
    }
}

void PlayerStateMachine::handleBtnMenu(EventQueue::Event event)
{
    switch(event.event_) {
    case EventType::btn_prev:
         exitMenuMode();
         break;
    case EventType::btn_play:
        bt_module_.enterPairingMode();
        exitMenuMode();
        break;
    case EventType::btn_next:
        enterSetClockMode();
        break;
    case EventType::btn_vol_up:
        bt_module_.resetPairings();
        display_.drawText(Display::TextPos::fullscreen, "All prior", "pairings cleared");
        delayMs(1800);
        exitMenuMode();
        break;
    case EventType::btn_vol_dn:
        NVIC_SystemReset();
        break;
    case EventType::btn_play_release:
    case EventType::btn_play_long_press:
    case EventType::rn52_gpio2:
    case EventType::rn52_state_chg:
    case EventType::track_chg:
    case EventType::proximity_trigger:
    case EventType::clock_tick:
    case EventType::do_nothing_event:
        break;
    }
}
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

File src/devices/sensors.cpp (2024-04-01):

#include <algorithm>
#include "sensors.h"
#include "drivers/sensors/bme280.h"
#include "drivers/sensors/vcnl_4200.h"
#include "serial/i2c.h"
#include "serial/i2c_bus_stm32f1xx.h"
#include "devices/peripherals.h"
#include "error_handler.h"

using namespace Libp;

constexpr uint32_t i2c_addr = I2C1_BASE;

static I2cWrapper i2c_wrap_bme_(i2c_bus, Bme280::i2c_addr_sdo_gnd);
static I2cWrapper i2c_wrap_prox_(i2c_bus, Vcnl4200::i2c_address);

static Bme280::Bme280 bme280_(i2c_wrap_bme_);
static Vcnl4200::Vcnl4200 vcnl4200_(i2c_wrap_prox_);

#ifndef MOCK_DATA

bool initTempSensor()
{
    return bme280_.initialize()
        && bme280_.reset()
        && bme280_.setConfig(Bme280::Mode::forced,
                // Don't change without updating measure_time_ms below
                Bme280::OSample::osample_x1, Bme280::OSample::osample_x1, Bme280::OSample::osample_x1,
                Bme280::TStandby::ts_10ms,
                Bme280::Filter::coef_16, false);
}
static constexpr uint16_t measure_time_ms = bme280_.maxMeasureTime(true, true, true, 1, 1, 1);


static constexpr Vcnl4200::Vcnl4200Cfg vcnl_cfg = []() {
    using namespace Vcnl4200;
    return Vcnl4200CfgBuilder()
            .alsEnable()
            .psEnable()
            .psLedSetDuty(PsLedDutyCycle::ratio_1_1280)
            .psLedSetDuration(PsLedDuration::it_4t)
            .psLedSetPulses(PsLedNPulses::x8)
            .psIntEnable(PsIntTrigger::closing, 0, 0, PsIntPersistence::x1)
            .build();
}();

uint16_t initProxSensor()
{
    using namespace Vcnl4200;
    bool success = vcnl4200_.configure(vcnl_cfg);

    constexpr uint16_t threshold_margin = 20;
    // Delay until sample is ready
    delayMs(250);
    const uint16_t count = vcnl4200_.psRead();
    const uint16_t threshold = count + threshold_margin;

    getErrHndlr().report("\r\nProx count %d. Threshold = %d\r\n", count, threshold);
    success = success && vcnl4200_.psSetThresholds(threshold, threshold);
    return success
            ? count
            : 0;
}

#ifdef TEST_PROX_MODE
uint16_t getProxCount()
{
    return vcnl4200_.psRead();
}
#endif

uint8_t clearProxInterrupt()
{
    return vcnl4200_.intFlags();
}


// Adjust for heating from proximity sensor/self.
// Using straight line at present until we have more data.
// Curve is specific to the prox sensor params above.
// y = mx + c
static constexpr float m = 1.1187;
static constexpr float c = -464.81;

bool getTemp(EnvData& env_data, uint32_t secsActive)
{
    // Trigger measure
    bool success = bme280_.setMode(Bme280::Mode::forced);
    if (!success)
        return false;

    delayMs(measure_time_ms);
    success = bme280_.getMeasurements(env_data);

    getErrHndlr().report("measured: %d\n", env_data.temperature);

    // Adjust for proximity sensor heating
//    env_data.temperature = 248;
    env_data.temperature = m * env_data.temperature + c;
    getErrHndlr().report("adjusted1: %d\n", env_data.temperature);

    // Adjust for general heating (~0.1deg/min, max 4min)
    env_data.temperature = env_data.temperature - std::min(secsActive, static_cast<uint32_t>(240)) * 0.15;
    getErrHndlr().report("adjusted2: %d\n", env_data.temperature);

    return success;
}

uint32_t getLightLvl()
{
    int32_t als = vcnl4200_.alsRead();
    if (als == -1)
        getErrHndlr().halt(ErrCode::i2c, "ALS read fail");

    return Vcnl4200::alsToMilliLux(als, Vcnl4200::AlsIntegTime::t50ms);
}

#else

bool initTempSensor()
{
    return true;
}

uint16_t initProxSensor()
{
    return 100;
}

uint8_t clearProxInterrupt()
{
    return 0;
}

bool getTemp(EnvData& env_data)
{
    static EnvData mock_data = {
        .pressure{1234},
        .temperature{2000},
        .humidity{47445}
    };
    if ( (mock_data.temperature += 50) == 3000)
        mock_data.temperature = 2000;
    env_data = mock_data;
    return true;
}

uint32_t getLightLvl()
{
    return 1500;
}

#endif

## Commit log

2020-03-12 Initial commit - PCB hardware production ver.A
    [bt_audio_rec-B_Cu.gbr, bt_audio_rec-B_Mask.gbr, bt_audio_rec-B_Paste.gbr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]
2020-09-09 Update proximity cap value, upate PCB notes.
    [bt_audio_rec.sch]
2020-09-22 Fix GPIO4 tied low and backwards MOSFET error
    [bt_audio_rec.kicad_pcb, bt_audio_rec.sch]
2020-09-23 Update connector label
    [bt_audio_rec.sch]
2020-09-23 Rename plot output folder
    [bt_audio_rec-B_Cu.gbr, bt_audio_rec-B_Mask.gbr, bt_audio_rec-B_Paste.gbr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]
2020-09-24 Connect unused pins to ground
    [bt_audio_rec.sch]
2020-09-25 Add duk.io logo
    [bt_audio_rec.kicad_pcb]
2020-09-26 Change LED resistor
    [bt_audio_rec.kicad_pcb, bt_audio_rec.sch]
2020-09-29 Add FPC pin number label
    [bt_audio_rec.kicad_pcb]
2020-10-14 Add decoupling cap to proximity LED
    See https://www.duk.io/blog/electronics-projects/bt-player/bluetooth-audio-player-firmware
    [bt_audio_rec.kicad_pcb, bt_audio_rec.sch]
2020-11-19 Add flyback label
    [bt_audio_rec.sch]
2024-03-29 Migrate to KiCad 7
    Update schematic/pcb and rescue symbols as required
    Move custom library to a project specific submodule
    Fix missing duk.io logo
    Update gitignore
    Remove old files
    [bt_audio_rec.kicad_pcb, bt_audio_rec.kicad_sch, bt_audio_rec.sch]
2024-04-01 Add project firmware
    [temp_adj.ods]
2024-04-01 Add hardware enclosure files
    [bt-wall-player.skp]

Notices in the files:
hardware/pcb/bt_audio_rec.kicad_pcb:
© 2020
